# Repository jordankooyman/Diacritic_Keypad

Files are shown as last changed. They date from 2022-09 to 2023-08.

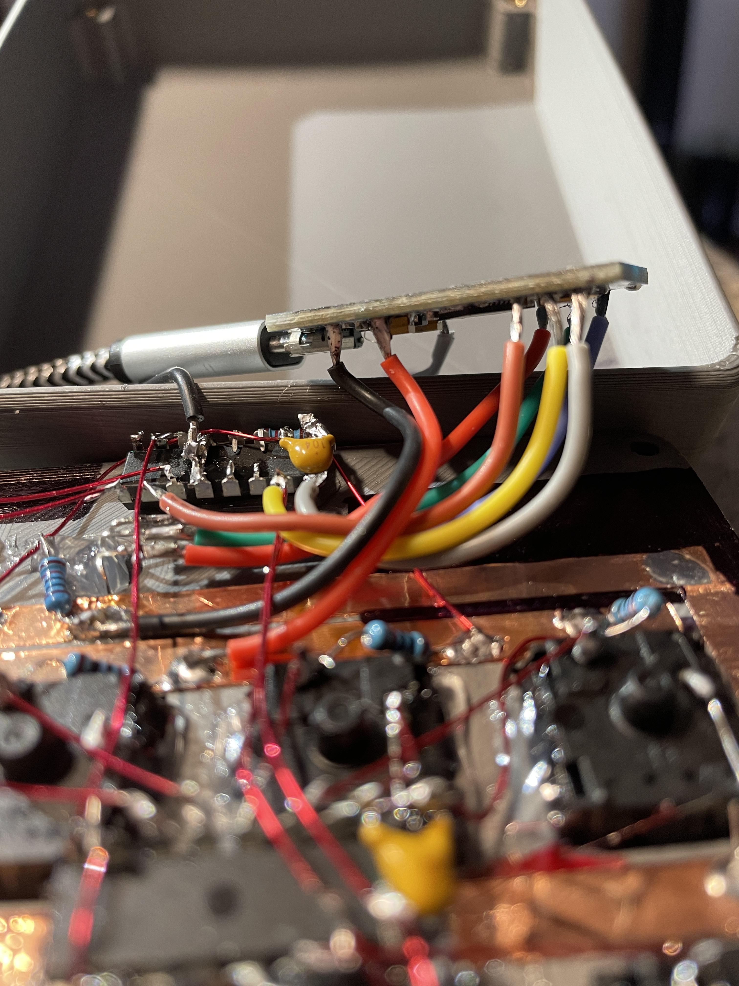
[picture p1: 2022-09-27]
Example Wiring Photos/Full Wiring with Capacitors (4).JPG

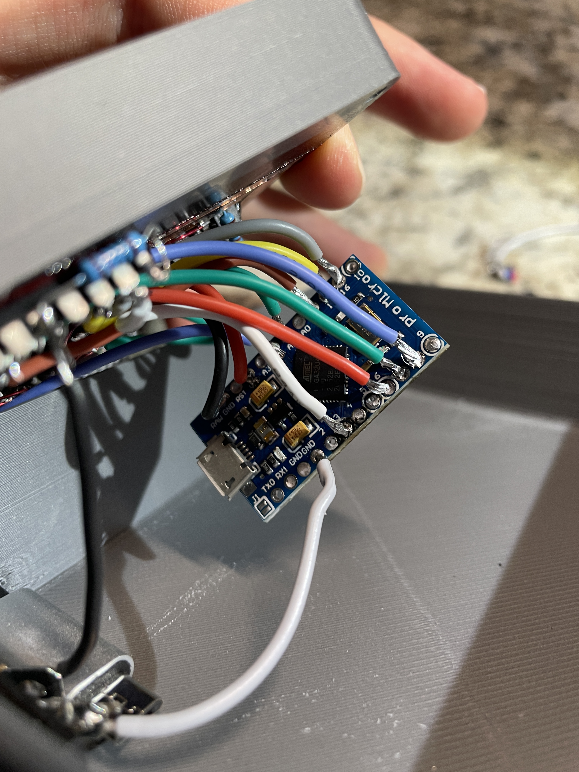
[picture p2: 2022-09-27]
Example Wiring Photos/Arduino Wiring (8).JPG

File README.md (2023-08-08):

# Diacritic_Keypad
An Arduino-based custom keyboard for more easily typing diacritic letters, particularly on Windows, but with support for many Linux distros as well.

Written for Arduino Pro Micro/Arduino Leonardo boards
Intended for use with 17 buttons and a switch, all connected to the arduino via chained shift registers
diacritc keypad finished perspective view

Bill of Materials (BOM):

    1x  RGB LED (common negative) for status indication at runtime
    17x Cherry MX Red keyswitches were used in my build, but any Cherry MX keyswitch should be compatible
    1x  Power switch style toggle switch (acts as Linux/Windows mode switch)
    3x  74HC165 Parallel to serial Shift Registers were used
    3x  0.1uF ceramic capacitors to stabalize shift registers
    1x  1uF electrolytic capacitor to handle larger current spikes - exact value not too important, can be larger
    1x  Arduino Pro Micro
    1x  6ft Micro USB to USB cable (glued in)
    19x 10k Resistors
        26awg Enamled copper wire for keyswitch connections
        Copper Foil tape for positive and negative bus bars (optional, but recommended)
        24awg Insulated copper wire for connections to arduino
        Pin headers to connect to arduino (optional)
        Hot Glue to hold in keyswitches and insulate shift registers
    4x  M3 brass heat-set inserts
    4x  M3 by 8mm bolts to hold everything closed
    1x  Case Set (case and insert) - must be 3D Printed (material choice not important)
    4x  Rubber Feet (optional)
    17x Keycaps (can be 3D Printed (material not important), sample files included)
diacritc keypad finished top view

All CAD files and example wiring pictures are included.
A sample set of keycaps is also included.
The two component reference pictures were sourced online, all other materials were made by Jordan Kooyman.

Basic wiring:  (Look at Example Wiring Photos folder included in this repo for an example)

    Every keyswitch (and toggle switch) is connected to GND (0V) directly.
    The other terminal on every keyswitch (and toggle switch) is connected to 1 data input pin on a shift register, with a 10k resistor also connecting that to Vcc (5V)
    The clock input pin on all 3 shift registers is connected together
    The parallel load input pin on all 3 shift registers is connected together
    The serial output pin of the shift register with only 2 connections is connected to the serial input pin of one of the other 2 shift registers
    Then, the serial output pin of that shift register is connected to the serial input pin of the final shift register
    The serial output, clock input, and parallel load input pins are all connected to I/O pins of the arduino
    Each shift register also needs the Vcc pin connected to Vcc (5V), GND to GND (0V), and Clock Enable connected to GND (0V)
    The common negative pin of the RGB LED is connected to a 10k resistor that is then connected to GND (0V)
    The other 3 pins of the RGB LED are connected to the I/O pins of the arduino
    The GND (0V) bus is conencted to a GND pin on the arduino
    The Vcc (5V) bus is conencted to the Vcc pin on the arduino
        Note: I recommend leaving some extra length on the wires that need to go from the top to the bottom (or vice versa) to
        make working on this easier (but make sure the case can still close)
    The electrolytic capacitor is connected between VCC (5v) and GND (0V) busses somewhere (ensure correct polarity, strip is negative pin)
    1 ceramic capacitor is connected between GND (0V) and the Vcc input pin of each shift register

Here is a video of me wiring my keypad together, uncut but running at 2x speed: https://youtu.be/HU2RTQba6jM

Due to the variability of wiring and desired character outputs, the code included is incomplete and all character combinations must be written in manually.

# Prevent Code Uploads
This keypad, as currently designed, will always still appear as an arduino device when connected to a computer. To change how it appears, but not restrict reprogrammability at all, the VID and PID values can be modified for the profile being uploaded to the board. To restrict reprogramming, some COM ports related to the attatched can be disabled in Windows, but it is local to each PC. To better restrict programming, an external ISP such as a usbTinyISP can be used to upload a the code and overwrite the bootloader of the Arduino Pro Micro. Note that overwriting the bootloader means that the ISP must be used to upload code to the board again in the future, until a bootloader is reloaded. Traditional methods of disabling sketch uploading to arduino boards do not work for the Atmega32u4 since it has built-in usb support rather than using an external chip, however this may be different if you are using a different microprocessor. For more information, please do your own research for the specific board you are using.

# Design and Wiring Advice
When designing your own case, it is important to keep in mind both how to assemble it and where all the wiring will go inside. Make sure to leave enough room on the inside to fit all the wires and the microcontroller such that no wires inadvertently short out once assembled, which may cause permanent damage to the microcontroller or worse. To make this easier, it is recommended to make the whole case from plastic rather than metal. If making the case from metal, make sure to insulate all connections to prevent short circuits (and be careful using the copper foil tape bus bar design demonstrated above since those tapes often feature a conductive adhesive). Before doing the final assembly of the project, make sure to carefully assembly throughout the build process to ensure everything will still fit together and nothing will short circuit. It is also recommended to test the wiring throughout, which can be accomplished by uncommenting the TestMode line in the code provided (it is uncommented as provided here) before testing all the parts believed to be fully functional while the device is plugged into a computer with Arduino IDE and the serial monitor open on the correct port.
While wiring, try to keep the wires organized. It is recommended to mark them if they are not unique, and to write down where each one goes until it can be fully connected. Also ensure the wires are long enough to reach to their destination and the device can still be opened, but not so long that there is a lot of extra wire when attempting to assemble the device.

# Testing Guide
To test operations of the device as well as to determine the button layout, the built-in TestMode allows you to see what the microcontroller reports when a button is pressed. This can be seen with the serial monitor running (included in Arduino IDE) with the device connected to that computer via USB. If any anomalies appear, such as a button not showing it is pressed, or always being pressed, or 1 button being pressed shows multiple buttons being pressed, the first thing that should be done is to verify the wiring is correct. Do this by using a multimeter with a continuity test and check both connections that should exist and connections that should not. If nothing can be found, check again with the serial monitor while the device is open for testing, as short circuits may occur only while assembled. If no faults can be found in the wiring, check the code to ensure it is reading the buttons correctly, particularly any changes you have made. Another common issue is not updating the pins that are used, which can lead to erratic behavior.

# Disclaimers
This project is licensed under GPLv3. As such, you are free to use this project and modify it as you see fit, both privately and commercially. However, if used commercially, the product must disclose this project as its source as well as all changes made. For more information, please check out the license directly.
You are fully responsible and liable for any faults, issues, damage, or other problems for any devices you make. Make at your own risk.

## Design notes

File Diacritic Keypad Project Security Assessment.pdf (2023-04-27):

Security Assessment – Diacritic Keypad

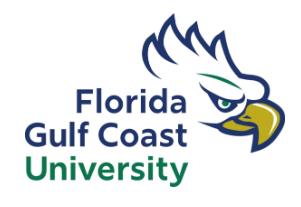
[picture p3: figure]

### Open-Source Keypad for Diacritic Characters

# Security Assessment Report

### Version 1.0

### April 27, 2023

Page ii

## Table of Contents

## 1. Summary

We have determined that the security of the open-source Diacritic Keypad project was mediocre through product observation and white box testing. The major issues were centered around lack of explanation of systems over bad design or implementation.

## 1. Assessment Scope

Arduino IDE on Windows 10 and Windows 11 was utilized during testing, with the C project code being tested. GitHub was tested through Firefox, Edge, and Chrome, focusing primarily on the content more than the formatting.

## 2. Summary of Findings

Of the findings discovered during our assessment, 1 was considered High risk, 0 Moderate risks, 2 Low, and 5 Informational risks. The SWOT used for planning the assessment are broken down

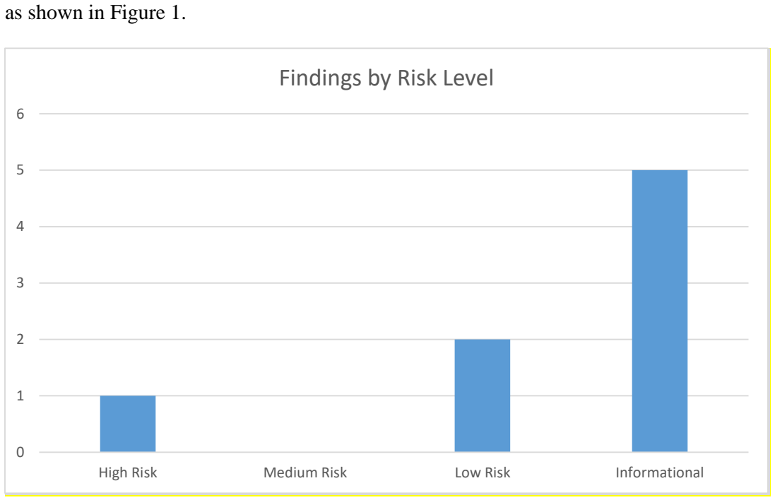
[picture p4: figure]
as shown in Figure 1.; High Risk; Medium Risk; Low Risk; Informational; Findings by Risk Level

Figure 1. Findings by Risk Level

The top risk was a simple issue that the code of the device when finalized can still be easily overwritten, leading to many issues for the end user, and the potential for dangerous security vulnerabilities to be added to an otherwise secure computer. The remaining risks were either already handled or were more minor changes focused on improving the explanations with the project.

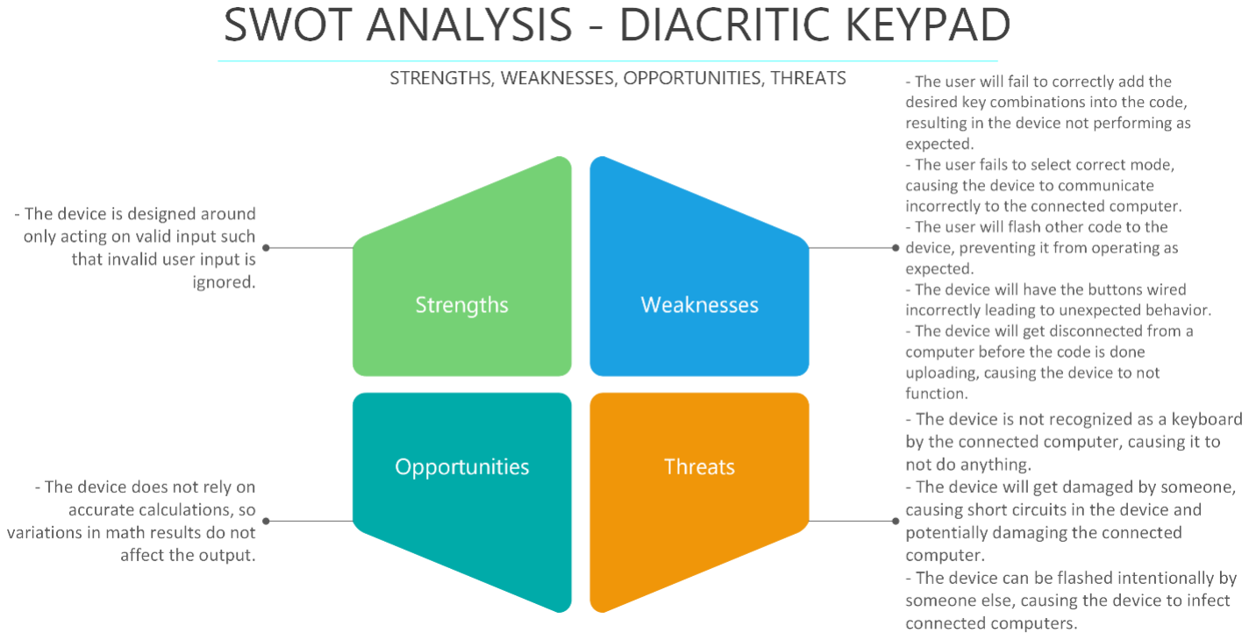
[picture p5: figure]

Figure 2. SWOT

The issues related to code being overwritten and bad assembly of project were addressed from the SWOT shown in Figure 2.

## 3. Summary of Recommendations

The provided supporting documentation and content needs to be improved to address assumptions made during the initial project, particularly focusing on assumed prior knowledge of electronics, wiring, and general safe practices of people considering attempting the project. Some guides have been built to address these issues, but more depth needs to be added to certain sections, such as modifying the code, as well as adding video-based content to demonstrate safe practices and techniques.

## 2. Goals, Findings, and Recommendations

## 1. Assessment Goals

The purpose of this assessment was to do the following:
- Ensure that the system was in compliance with basic user security as defined in CEN 3078.
- Determine if the application was securely built.
- Assess necessary corrective measures to reduce or eliminate identified issues.

## 2. Detailed Findings

Type | Severity | Detailed Finding
Weakness | Informational | The project code uses several C-style arrays throughout to store state data and reference keys. These arrays are easy to look beyond the bounds of as they decay to pointers readily, as discussed in CEN 3073 lecture on March 30th, 2023, particularly in loops, which is how this project utilizes the arrays.
Threat | Informational | The project is based on responding to user input, and not all inputs are valid, since only specific combinations of keys will produce a valid diacritic character, so faulty user input must be considered in every section that takes input from the user to ensure all scenarios are handled, even unexpected scenarios.
Threat | Moderate Risk

The code stored on hobby use microcontrollers such as the recommended Arduino Pro Micro have a built-in bootloader to allow for code to be easily uploaded when a computer is connected, as discussed online in the forum thread “Arduino pro Micro -Is It Possible to Remove the Bootloader While Flashing Using the Bootloader?”. However, this project intends to leave the microcontroller always connected to the computer, therefore code can always be written to it, overwriting the previous code, which can lead to unintended outcomes if the device is completed and another project’s code gets uploaded to this device.

Weakness | High Risk | The project code assumes that the pins defined at the top are correct, and if they are not updated to match each instance of the project built, the project may not work as intended or at all, as the communication wires expected are not actually there, but the code has no checks for such a condition.
Weakness | High Risk | The project requires that everything is wired correctly with no short circuits and the correct components. If this is not the case, the project is very likely to not function at all and even has the risk to physically damage components including the microcontroller and potentially also connected computers.
Threat | Observation | This project’s code includes 1 library, ‘Keyboard.h’. Since this library is included, the security of it must also be assessed since it is adding code to the project as well as being actively and extensively used in the project. However, due to the scale of the Arduino Pro Micro and the wide variance of it, there is very little focus on security holes in the library that may exist, as seen in the issues for the code on GitHub (“Issues · Arduino-Libraries/Keyboard.”). Most focus is instead pointed towards how the library can be used in security attacks on other systems, as seen by the research done by Seth Helgeson, et al., among many others.
Threat | Observation | The design of the project, particularly the case for the project, is very important as well. A poorly designed case will not hold things tightly and securely together, leading to the wires potentially getting ripped off, crushed, broken, touching each other (short circuit), or otherwise being exposed to being damaged over time. Many of these issues will not appear immediately but will instead manifest over time, leading to erratic behavior long after the project is completed, making the issue hard to identify for inexperienced users.
Weakness | Low Risk | This project features only minimal logging in the form of a debugging and test mode that can be enabled and disabled within the code. Additionally, even when this logging is occurring, a serial monitor must be running on an attached computer in order to see any of the log data as it occurs, as no information is saved to the microcontroller. Furthermore, no information is logged during normal use.

## 3. Recommendations

1. Add a Design and Wiring Advice section in ReadMe.md to help avoid potential

regulatory issues by advising people to tailor their designs to be safe and not pose a risk of electric shock or could otherwise cause damage to other systems. Ease of fix:

Moderately Difficult – guide must be thoroughly written to be most effective.

2. Add a testing guide section in ReadMe.md to provide some basic training on how to test

a project such as this for people with no prior experience. Also explain how to utilize the

basic logging systems included in the provided code, since it is real-time only and done

through the serial monitor in Arduino IDE. Ease of fix: Moderately Difficult – guide

must be thoroughly written to be most effective.

3. Update end of ReadMe.md with fair use licensing remark and end user risk disclaimer.

Ease of fix: Easy – simple template to follow, partially provided in GitHub (“Licensing a

Repository.”).

4. Vulnerabilities in included libraries (Keyboard.h). Perform extensive online research to

identify any known and relevant security vulnerabilities included in that library. Ease of

fix: Moderately Difficult – must check many sources and patch notes for issues.

5. Physical security of actual hardware. Add a disclaimer in the project ReadMe.md to make

users aware of the risks they must consider for their situation when designing and

building this product. Ease of fix: Easy – not an extensive guide, just a disclaimer.

6. Fix product code being overwritten. Update the ReadMe.md file of the project detailing

different things that can be done to reduce or eliminate this vulnerability. Ease of fix:

Moderately Difficult – guide must be thoroughly written for users not familiar with

alternative bootloader tools (“Disabling Skethc Uploading on Arduino pro Micro.”).

7. Add security design considerations section (including issues with adding wireless

connectivity). Ease of fix: Moderately Difficult – many scenarios to consider, but not an

extensive guide.

8. Update logging option to code, primarily for debugging, but with EEPROM as an option

if desired. Ease of fix: Difficult – need to restructure code and deal with creating and

exporting files.

## 3. Methodology for the Security Control Assessment

### 3.1.1 Risk Level Assessment

Each Business Risk has been assigned a Risk Level value of High, Moderate, or Low. The rating is, in actuality, an assessment of the priority with which each Business Risk will be viewed. The definitions in Error! Reference source not found. apply to risk level assessment values (based on probability and severity of risk). While Table 2 describes the estimation values used for a risk’s “ease-of-fix”.

Table 1 - Risk Values
Rating | Definition of Risk Rating
High Risk | Exploitation of the technical or procedural vulnerability will cause substantial harm to the business processes. Significant political, financial, and legal damage is likely to result
Moderate Risk | Exploitation of the technical or procedural vulnerability will significantly impact the confidentiality, integrity and/or availability of the system, or data. Exploitation of the vulnerability may cause moderate financial loss or public embarrassment to organization.
Low Risk | Exploitation of the technical or procedural vulnerability will cause minimal impact to operations. The confidentiality, integrity and availability of sensitive information are not at risk of compromise. Exploitation of the vulnerability may cause slight financial loss or public embarrassment
Informational | An “Informational” finding, is a risk that has been identified during this assessment which is reassigned to another Major Application (MA) or General Support System (GSS). As these already exist or are handled by a different department, the informational finding will simply be noted as it is not the responsibility of this group to create a Corrective Action Plan.
Observations | An observation risk will need to be “watched” as it may arise as a result of various changes raising it to a higher risk category. However, until and unless the change happens it remains a low risk.

Table 2 - Ease of Fix Definitions
Rating | Definition of Risk Rating
Easy | The corrective action(s) can be completed quickly with minimal resources, and without causing disruption to the system or data
Moderately Difficult | Remediation efforts will likely cause a noticeable service disruption • A vendor patch or major configuration change may be required to close the vulnerability • An upgrade to a different version of the software may be required to address the impact severity • The system may require a reconfiguration to mitigate the threat exposure • Corrective action may require construction or significant alterations to the manner in which business is undertaken
Very Difficult | The high risk of substantial service disruption makes it impractical to complete the corrective action for mission critical systems without careful scheduling • An obscure, hard-to-find vendor patch may be required to close the vulnerability

Rating | Definition of Risk Rating
| • Significant, time-consuming configuration changes may be required to address the threat exposure or impact severity • Corrective action requires major construction or redesign of an entire business process
No Known Fix | No known solution to the problem currently exists. The Risk may require the Business Owner to: • Discontinue use of the software or protocol • Isolate the information system within the enterprise, thereby eliminating reliance on the system In some cases, the vulnerability is due to a design-level flaw that cannot be resolved through the application of vendor patches or the reconfiguration of the system. If the system is critical and must be used to support on-going business functions, no less than quarterly monitoring shall be conducted by the Business Owner, and reviewed by IS Management, to validate that security incidents have not occurred

### 3.1.2 Risk Assessment

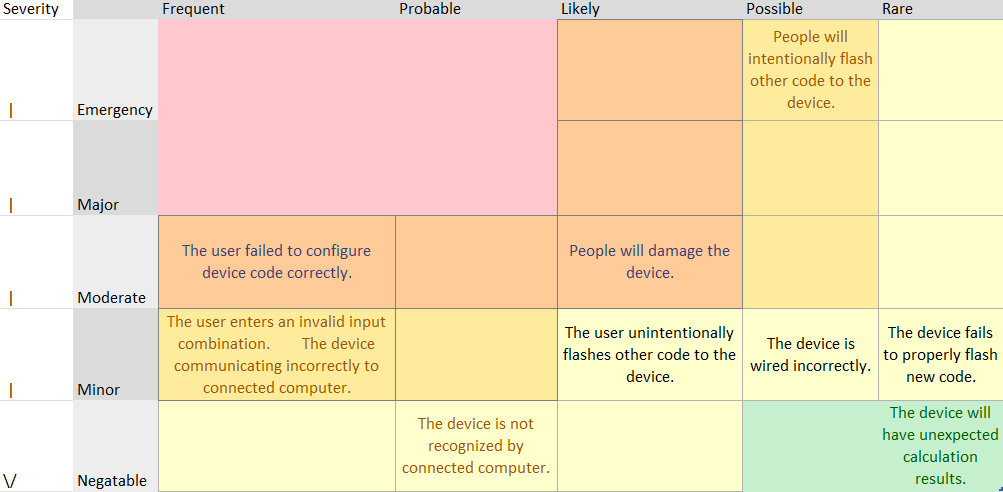
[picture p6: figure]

explain accuracy of it (what was and what wasn’t)

### 3.1.3 White Box Testing

This was completed by checking both known-valid and known-invalid inputs on the device and verify the code can handle the all the inputs without breaking or otherwise working in unexpected or undocumented ways.

### 3.1.4 Tools Used

This was completed using Arduino IDE’s Serial Monitor and dedicated serial port logging code in the project. Used to verify all button inputs work as expected, as well as key layout is known, and that there are no logical errors within the code, particularly since this part is defined by the end user and cannot be tested ahead of time.

### 3.1.5 Arduino Vulnerabilities

There are few major vulnerabilities in the Arduino hardware, specifically the Arduino Pro Micro, based on the ATMega32u4 processor. There are also no known vulnerabilities in the only included file in the C code of the project, Keyboard.h, at least as reported to the library’s issues tracker in GitHub (“Issues · Arduino-Libraries/Keyboard.”). There is currently very little interest in trying to hack these devices and libraries since they simply are not widespread enough nor containing valuable enough information for most hackers to target these, instead they may focus on consumer units that are similar but using different code and hardware (“Security Risk of Emulating Hid Devices with ATmega32U4 Devices.”). The only major attention focused on these type of devices is how they can be utilized in attacks of other systems, primarily when a USB port can be accessed (Helgeson, Seth, et al.).

## 4. Figures and Code

### 4.1.1 Processing Cycle Flowchart

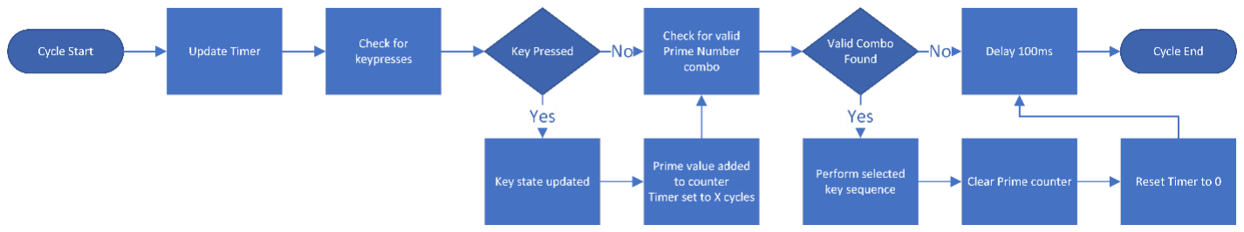
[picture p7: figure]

The processing flowchart shown above describes the execution path of the project code in a high level, including the branches reacting to user input, when it is given.

### 4.1.2 Project Build and Test Flowchart

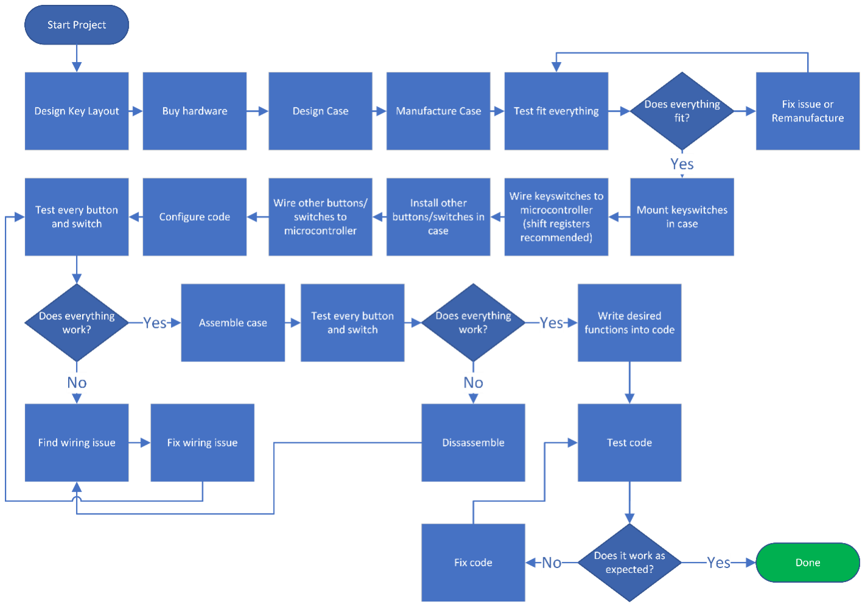
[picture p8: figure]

The flowchart above details all the steps for completing this project as an outside user. Includes all steps between starting the project and having a complete and working product. The process has many points for users to make changes, necessitating several checks throughout that cannot be done by the project itself.

### 4.1.3 Sample Logging Code

// Print out extra debug information if enabled #ifdef ExtendedTestMode
Serial.print("Button Index: "); Serial.print(button);
Serial.print(" Value: ");
Serial.println(value);
#endif

The code snippet shown above is a sample of the logging code currently in the project’s code. This section and several others could be expanded to include writing to an internal file. In adding that feature, another function would also need to be added for exporting that internal file to a computer to be used for debugging or maintenance.

## 5. Works Cited

“Arduino pro Micro - Is It Possible to Remove the Bootloader While Flashing Using the Bootloader?” Arduino Stack Exchange, arduino.stackexchange.com/questions/90543/is-it-possible-to-remove-the-bootloader-while-flashing-using-the-bootloader. Accessed 26 Apr. 2023.
“Disabling Skethc Uploading on Arduino pro Micro.” Arduino Forum, 2 Nov. 2022, forum.arduino.cc/t/disabling-skethc-uploading-on-arduino-pro-micro/1048808. Accessed 26 Apr. 2023.
“Issues · Arduino-Libraries/Keyboard.” GitHub, github.com/arduino-libraries/Keyboard/issues?q=is%3Aissue. Accessed 26 Apr. 2023.
“Licensing a Repository.” GitHub Docs, docs.github.com/en/repositories/managing-your-repositorys-settings-and-features/customizing-your-repository/licensing-a-repository#disclaimer.
“Security Risk of Emulating Hid Devices with ATmega32U4 Devices.” Arduino Forum, 5 July 2021, forum.arduino.cc/t/security-risk-of-emulating-hid-devices-with-atmega32u4-devices/881892. Accessed 26 Apr. 2023.
Helgeson, Seth, et al. Wireless Exploitation through Keyboard Emulation. Athens: The Steering Committee of The World Congress in Computer Science, Computer Engineering and Applied Computing (WorldComp), 2018. ProQuest. Web. 26 Apr. 2023.
Week 11 Lecture – March 30th
- about code vulnerabilities (c-style arrays and pointers)

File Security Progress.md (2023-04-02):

Security Fixes:
1. Vulnerabilities in included libraries. I only include 1 library in this code (Keyboard.h). After extensive online research, I have found no known relevant security vulnerabilities included in that library. Therefore, no changes need to be considered in the code regarding this library.
2. Physical security of actual hardware. Due to the nature of the product and project, very little can be done to improve the physical security of each keypad. This is because this project focuses on providing a design for a keypad that other people can use as a starting point and modify to meet their needs. Therefore, the target use case is very broad and involves very different physical security considerations, thus it will go against the nature of the project to include physical security precautions in the design. However, a disclaimer was added in the ReadMe.md file of the project in [commit e0c8cb9](https://github.com/jordankooyman/Diacritic_Keypad/blob/e0c8cb98c9d53e41b8528363b02cca5fffdffaf5/README.md).
3. Fix product code being overwritten. To prevent the code from being overwritten accidentally or maliciously, several methods have been added to the ReadMe.md file of the project detailing different things that can be done to reduce or eliminate this vulnerability. These were added in [commit e0c8cb9](https://github.com/jordankooyman/Diacritic_Keypad/blob/e0c8cb98c9d53e41b8528363b02cca5fffdffaf5/README.md).

Upcoming Fixes:
1. Add security design considerations section (including issues with adding wireless connectivity). Priority: Mid Difficulty: Moderate
2. Add tutorial sections for different ways to fix code overwrite problem. Priority: High Difficulty: Moderate
3. Add logging option to code, primarily for debugging, but with EEPROM as an option if desired. Priority: Low Difficulty: Difficult
4. Add suggested product test procedure to project to help with debugging and building. Priority: Mid Difficulty: Easy

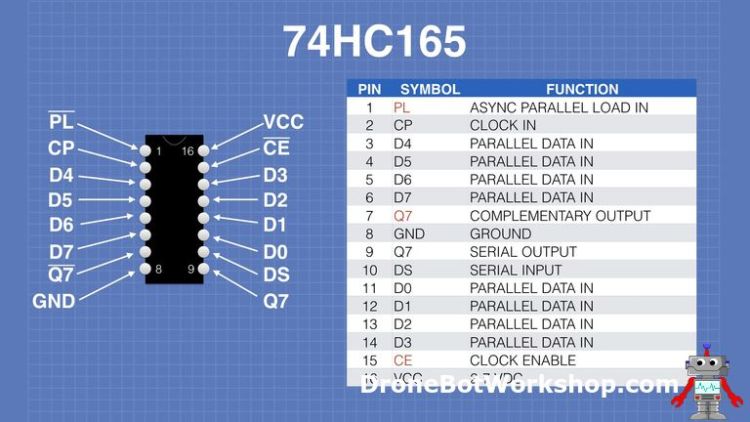
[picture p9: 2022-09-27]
Example Wiring Photos/74HC165-pinout.jpeg

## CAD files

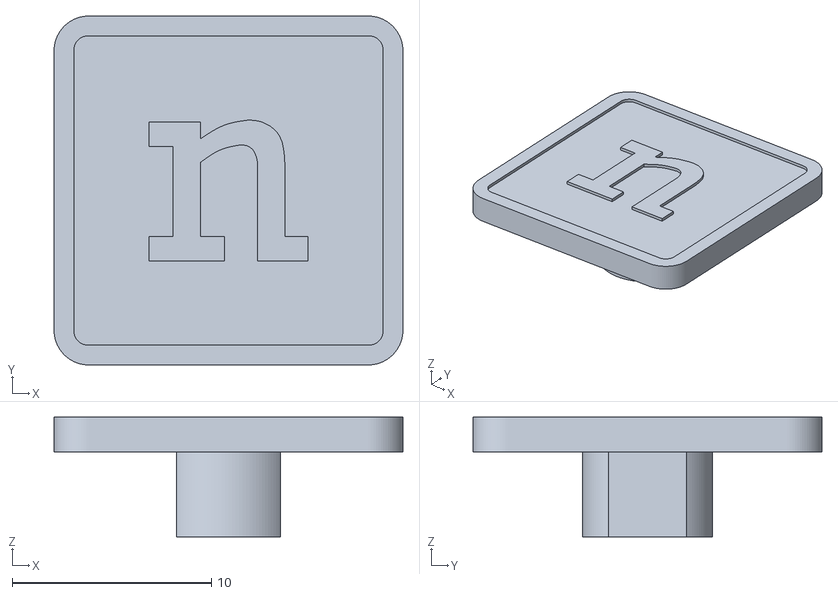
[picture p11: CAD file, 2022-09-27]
3D CAD Files/Diacritic Keycaps (Sample)/n Keycap.obj
17.5 x 17.5 x 6.00

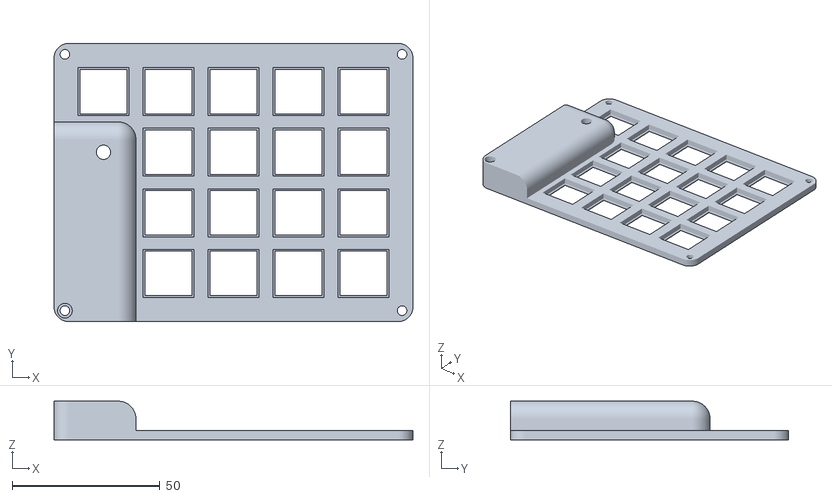
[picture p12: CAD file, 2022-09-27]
3D CAD Files/Key Insert.stl
121.5 x 94.2 x 13.1

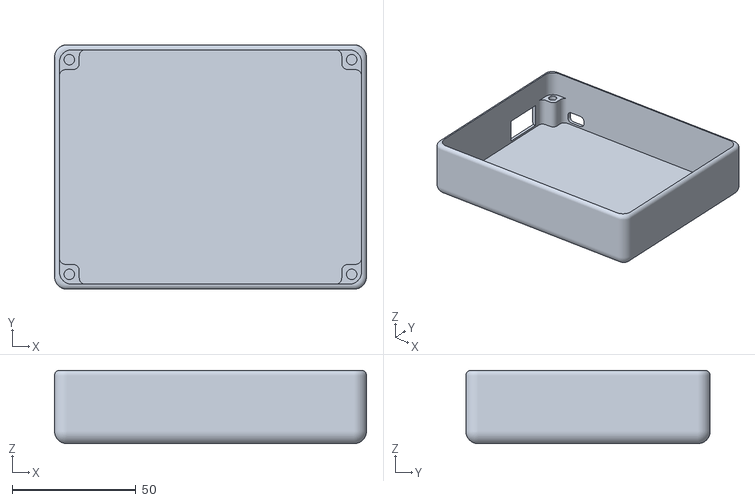
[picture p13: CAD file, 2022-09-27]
3D CAD Files/Case.stl
126.1 x 98.7 x 29.6

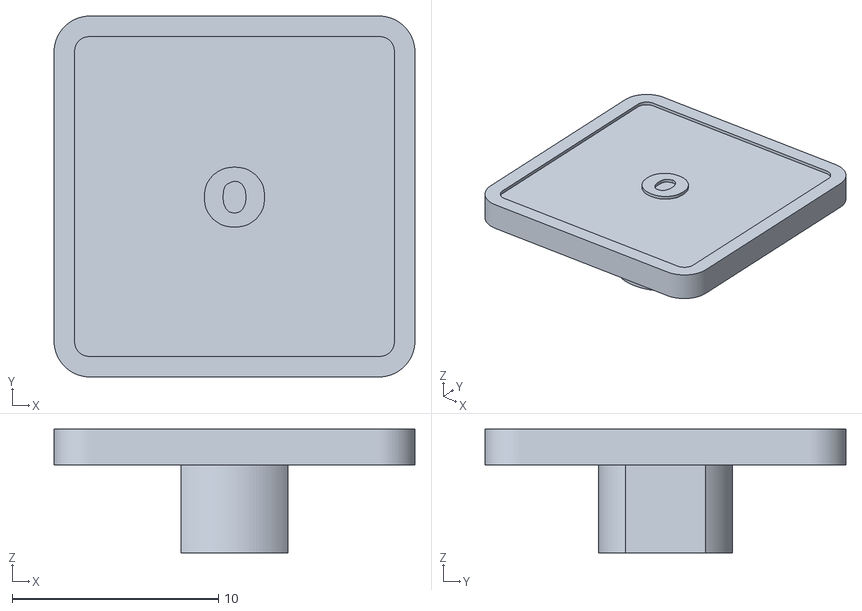
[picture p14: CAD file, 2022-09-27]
3D CAD Files/Diacritic Keycaps (Sample)/O Keyacp.obj
17.5 x 17.5 x 6.00

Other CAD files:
3D CAD Files/Diacritic Keycaps (Sample)/Shift Keycap.obj
3D CAD Files/Diacritic Keycaps (Sample)/e Keycap.obj
3D CAD Files/Diacritic Keycaps (Sample)/c Keycap.obj
3D CAD Files/Diacritic Keycaps (Sample)/a Keycap.obj
3D CAD Files/Diacritic Keycaps (Sample)/o Keycap.obj
3D CAD Files/Diacritic Keycaps (Sample)/u Keycap.obj
3D CAD Files/Diacritic Keycaps (Sample)/i Keycap.obj
3D CAD Files/Diacritic Keycaps (Sample)/' Keycap.obj
3D CAD Files/Diacritic Keycaps (Sample)/'' Keycap.obj
3D CAD Files/Diacritic Keycaps (Sample)/, Keycap.obj
3D CAD Files/Diacritic Keycaps (Sample)/Keycap.obj
3D CAD Files/Diacritic Keycaps (Sample)/^ Keycap.obj
3D CAD Files/Diacritic Keycaps (Sample)/` Keycap.obj
3D CAD Files/Diacritic Keycaps (Sample)/~ Keycap.obj
3D CAD Files/Source Files/Diacritic Keycaps.f3d
3D CAD Files/Source Files/Diacritic Keypad.f3d

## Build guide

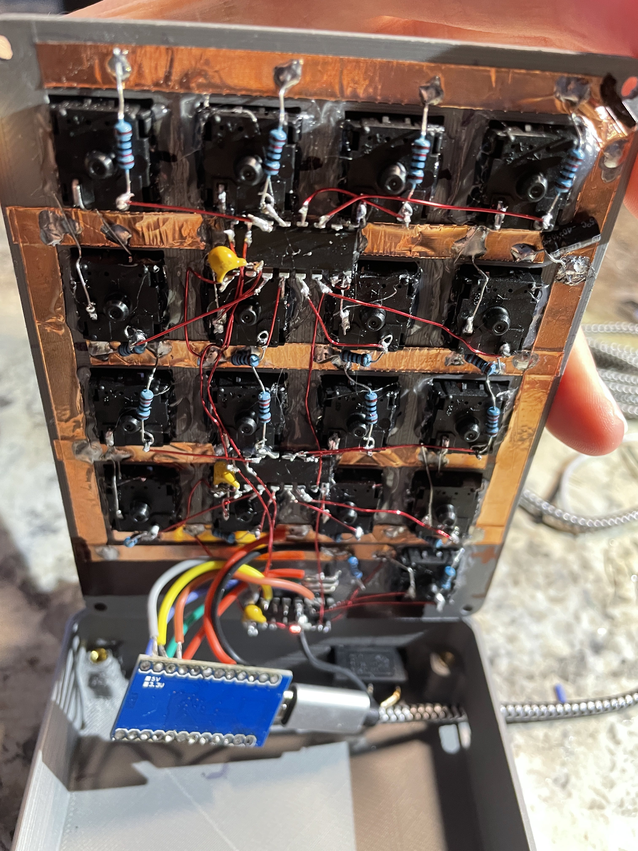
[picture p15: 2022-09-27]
Example Wiring Photos/Full Wiring with Capacitors (8).JPG

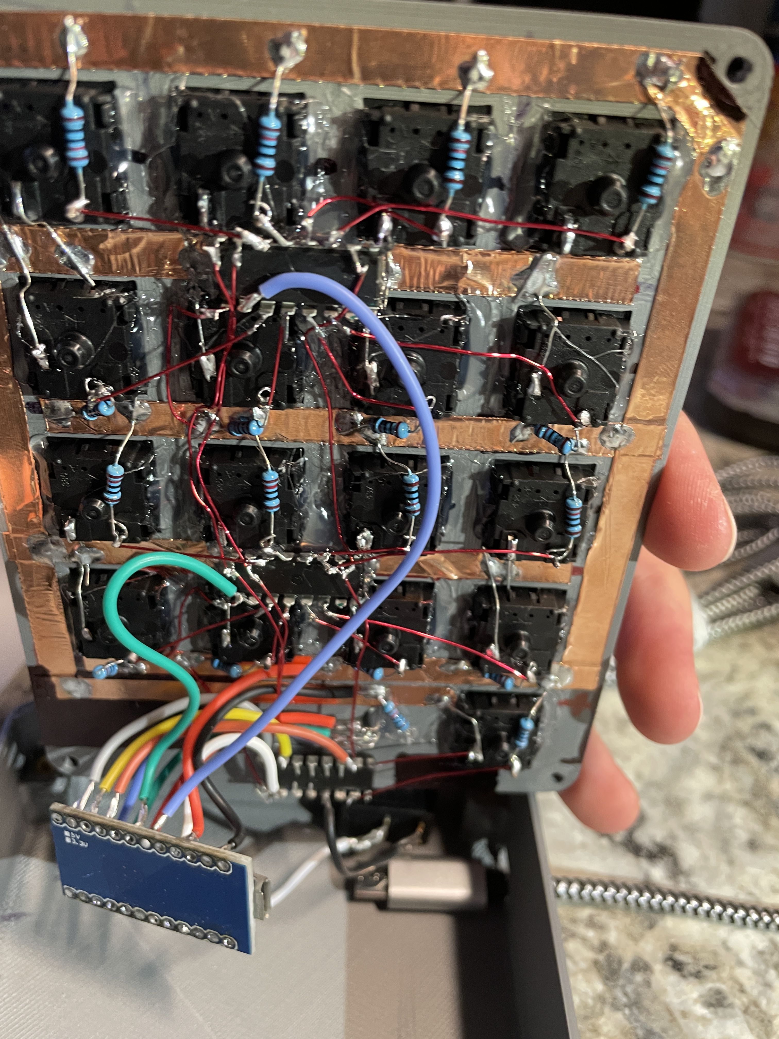
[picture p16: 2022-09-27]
Example Wiring Photos/Arduino Wiring (1).JPG

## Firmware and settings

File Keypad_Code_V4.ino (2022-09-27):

// Diacritic Keypad program by Jordan Kooyman
// Completed 9/27/22
// Written for Arduino Pro Micro/Arduino Leonardo boards
// Intended for use with 17 buttons and a switch, all connected to the arduino via chained shift registers
// Uses 1 RGB LED (common negative) for status indication at runtime
// More information can be found at: https://github.com/jordankooyman/Diacritic_Keypad

// Only 1 sample output is provided using demo numbers, all the output cases (starting at line 180)
//   will need to be written manually once key layout is determined

// Basic Program Configuration:

//Debug Mode Compiler Controls
#define TestMode 1 // Comment out to disable test mode and enable normal keyboard output
#define ExtendedTestMode 1 // Comment out to disable per button press debug information

//Define where each pin is connected to the Ardunio-compatible board
#define PIN_CLOCK 14    // Shift Register Clock Pin
#define PIN_LOADDATA 16 // Shift Register Load Data Pin
#define PIN_DATAIN 15   // Shift Register Data Output Pin
                        // Shift Register Enable Pin -> connect to VCC (5V) to always enable
#define PIN_RED 6       // RGB LED Red leg
#define PIN_GREEN 7     // RGB LED Green leg
#define PIN_BLUE 8      // RGB LED Blue leg

// Keyboard ID/index layout: - Verify using extended test mode (dependent on wiring)
//    0     9   2  17  10
//    1     8   3  16  11
//          7   4  15  12
//          6   5  14  13
// Keyboard Prime Mapping:   - Rearrange as needed such that prime numbers are increasing as key id increases
//         19   2  53  23
//         17   3  47  29
//         13   5  43  31
//         11   7  41  37
// Keyboard Key Mapping:     - Fill in after desired key layout has been determined
// Shift    ?   ?   ?   ?
//  Mode    ?   ?   ?   ?
//          ?   ?   ?   ?
//          ?   ?   ?   ?

const int primeTable[16] = {2,3,5,7,11,13,17,19,23,29,31,37,41,43,47,53}; // Used to decode combination in switch statement
  // Corresponding keys:  ?,?,?,?, ?, ?, ?, ?, ?, ?, ?, ?, ?, ?, ?, ?
int buttonState[18] = {-1,-1,-1,-1,-1,-1,-1,-1,-1,-1,-1,-1,-1,-1,-1,-1,-1,-1}; 
// Corresponding keys:  ?, ?, ?, ?, ?, ?, ?, ?, ?, ?, ?, ?, ?, ?, ?, ?, ?, ?

// Debugging Mode Indicator Outputs
#define WINDOWS_OUTPUT "Windows: "
#define LINUX_OUTPUT "Linux: "

// End of Basic Program Configuration

// Advanced Program Configuration, No Changes Recommended

// Define numpad constants for windows altcode usage - https://www.reddit.com/r/arduino/comments/c3cl41/keyboard_library_using_alt_keycodes_trouble/
// Custom data type to simplify handling of numpad inputs for Windows altcode combinations
enum NumPad {
  N_SKIP = -1,    // Skip given key for output
  N_1 = 0xE1, // Keypad 1 and End
  N_2 = 0xE2, // Keypad 2 and Down Arrow
  N_3 = 0xE3, // Keypad 3 and PageDn
  N_4 = 0xE4, // Keypad 4 and Left Arrow
  N_5 = 0xE5, // Keypad 5
  N_6 = 0xE6, // Keypad 6 and Right Arrow
  N_7 = 0xE7, // Keypad 7 and Home
  N_8 = 0xE8, // Keypad 8 and Up Arrow
  N_9 = 0xE9, // Keypad 9 and Page Up
  N_0 = 0xEA  // Keypad 0 and Insert
};


#ifndef TestMode
#include <Keyboard.h> // https://www.arduino.cc/reference/en/language/functions/usb/keyboard/
#endif

bool Shift = false;
bool OS = false; //False: Windows  |  True: Linux
int value;
int total;
unsigned long clock;

// Windows altcodes, with support for 3 or four digits
void pressWindows(String output, NumPad key1, NumPad key2, NumPad key3, NumPad key4 = N_SKIP); 
// Linux altcode handled with unicode hex values (0-9 and A-F, case sensitive)
void pressLinux(String output, char key1, char key2, char key3, char key4);

void setup() { //Initialize pins as i or o for test-proofing
  pinMode(PIN_CLOCK, OUTPUT);
  pinMode(PIN_LOADDATA, OUTPUT);
  pinMode(PIN_DATAIN, INPUT);
  pinMode(PIN_RED, OUTPUT);
  pinMode(PIN_GREEN, OUTPUT);
  pinMode(PIN_BLUE, OUTPUT);
  #ifdef TestMode
  Serial.begin(9600);
  #else
  Keyboard.begin();
  #endif
}

// End of Advanced Program Configuration

void loop() {
  value = -1;
  digitalWrite(PIN_CLOCK, 1); //Initializes pins to low each cycle to avoid false positives
  digitalWrite(PIN_RED, 0);
  digitalWrite(PIN_GREEN, 0);
  digitalWrite(PIN_BLUE, 1);
  digitalWrite(PIN_LOADDATA, 0); // Load data into shift registers
  digitalWrite(PIN_CLOCK, 0);
  digitalWrite(PIN_CLOCK, 1);
  digitalWrite(PIN_LOADDATA, 1);
  
  //Update LED Status to default (red) and reset running total to 1 if timer expires (no longer greater than system timer)
  if (clock <= millis())
  {
    digitalWrite(PIN_RED, 1);
    digitalWrite(PIN_GREEN, 0);
    digitalWrite(PIN_BLUE, 0);
    total = 1;
    #ifdef TestMode
    Serial.println("LED Red");
    #endif
  }

  for (int button = 0; button < 18; button++) { // Load in 18 bits of data from the 3 shift registers connected as 1 24 bit register
    if (button == 2) { // skip the unused pins on the first shift register
      digitalWrite(PIN_CLOCK, 0);
      digitalWrite(PIN_CLOCK, 1); 
      digitalWrite(PIN_CLOCK, 0);
      digitalWrite(PIN_CLOCK, 1);
      digitalWrite(PIN_CLOCK, 0);
      digitalWrite(PIN_CLOCK, 1);
      digitalWrite(PIN_CLOCK, 0);
      digitalWrite(PIN_CLOCK, 1);
      digitalWrite(PIN_CLOCK, 0);
      digitalWrite(PIN_CLOCK, 1);
      digitalWrite(PIN_CLOCK, 0);
      digitalWrite(PIN_CLOCK, 1);
    }
    // Read in the next bit of data from the shift registers
    value = digitalRead(PIN_DATAIN);

    //Determine if the button state has changed, if so store the change and optionally output debug info to serial monitor
    if(buttonState[button] != value)
  { //Potentially add a flag to send to processing
      buttonState[button] = value;
    if (button == 0) Shift = value; // If shift button state changes, update the shift flag
    else if (button == 1) OS = value; // If the OS switch state changes, update the os flag
    else if (value) // If a regular button is pressed, multiply the running total by its prime number and update LED
    {
      total *= primeTable[button-2]; 
      clock = millis() + 1000; // Add 1,000 milliseconds to the timer and set LED to blue
      digitalWrite(PIN_RED, 0);
      digitalWrite(PIN_GREEN, 0);
      digitalWrite(PIN_BLUE, 1);
      #ifdef TestMode
      Serial.println("LED Blue");
      #endif
    }
  // Print out extra debug information if enabled
  #ifdef ExtendedTestMode
    Serial.print("Button Index: ");
    Serial.print(button);
    Serial.print("    Value: ");
    Serial.println(value);
  #endif
    }

    //Pulse the clock to get next bit of data
    digitalWrite(PIN_CLOCK, 0);
    digitalWrite(PIN_CLOCK, 1);
  }
  
  
  //Start processing the data here  
  bool validCombo = false;


  // Every combination needs to be added within the following statement (inside the { })
  // Each different combination needs a new case, but uppercase and lowercase are handled in the same block
  // It is recommended to copy everything starting at 'case (...' to '...break; // end ...' and paste as needed, changing each subsequent block for the next combination
  
  switch (total)
  {
  case (19*17): // begin ae - 19 * 17 [Example case, numbers likely need to be changed]
    if(Shift)       // Uppercase
      if (OS) // Linux
        pressLinux("AE - 00C6", '0', '0', 'C', '6');
      else    // Windows
        pressWindows("AE - 146", N_1, N_4, N_6);
    else            // Lowercase
      if (OS) // Linux
        pressLinux("ae - 00E6", '0', '0', 'E', '6');
      else    // Windows
        pressWindows("ae - 145", N_1, N_4, N_5);
    validCombo = true; // Update Status LED after logic
    break; // end ae - 19 * 17 [Example case, numbers likely need to be changed]
  case 2: // Keep logic going here (remove this line)
    break; // Remove this line as well
  }


  
  
  if(validCombo) // Update status LED if combo found
  {
    total = 1; // Reset running total to 1 to prevent sending repeated inputs
    clock = millis() + 10000; // Add 10,000 milliseconds (10 seconds) to the timer and set LED to green
    digitalWrite(PIN_RED, 0);
    digitalWrite(PIN_GREEN, 1);
    digitalWrite(PIN_BLUE, 0);
    #ifdef TestMode
    Serial.println("LED Green");
    #endif
  }

  delay(100); // Pause execution for 100 milliseconds to keep program running at a reasonable speed (1000/100 = runs nearly 10 times per second)
}


/**
* Processes given altcode to output to Windows through keyboard emulation, with support for 3 or 4 digit altcodes
* Additionally, has a debug mode that can be enabled globally at the top of the code
* @param output - character combination altcode represents, for function debugging and readability
* @param key1 - first number in altcode sequence
* @param key2 - second number in altcode sequence
* @param key3 - third number in altcode sequence
* @param key4 - (optional) fourth number in altcode sequence
* @return void
*/
void pressWindows(String output, NumPad key1, NumPad key2, NumPad key3, NumPad key4) {
  #ifdef TestMode
  Serial.println(WINDOWS_OUTPUT + output);
  #else // Keyboard Output
  Keyboard.press(KEY_RIGHT_ALT);
  
  if (key1 != KEY_SKIP)
    Keyboard.write(key1);
  if (key2 != KEY_SKIP)
    Keyboard.write(key2);
  if (key3 != KEY_SKIP)
    Keyboard.write(key3);
  if (key4 != KEY_SKIP)
    Keyboard.write(key4);
  
  Keyboard.releaseAll();
  #endif
  return;
}


/**
* Processes given hexadecimal unicode to output to many Linux distros through keyboard emulation
* Additionally, has a debug mode that can be enabled globally at the top of the code
* @param output - character combination unicode represents, for function debugging and readability
* @param key1 - first number in hexadecimal unicode sequence
* @param key2 - second number in hexadecimal unicode sequence
* @param key3 - third number in hexadecimal unicode sequence
* @param key4 - fourth number in hexadecimal unicode sequence
* @return void
*/
void pressLinux(String output, char key1, char key2, char key3, char key4) {
  #ifdef TestMode
  Serial.println(LINUX_OUTPUT + output);
  #else // Keyboard Output
  Keyboard.press(KEY_RIGHT_SHIFT);
  Keyboard.press(KEY_RIGHT_CTRL);
  Keyboard.press(KEY_U);
  
  Keyboard.write(key1);
  Keyboard.write(key2);
  Keyboard.write(key3);
  Keyboard.write(key4);
  
  Keyboard.press(KEY_RETURN); // Enter key to close combination
  Keyboard.releaseAll();
  #endif
}

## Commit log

2022-09-27 Update README.md with more complete description
    Added A BoM, wiring description, demo wiring video, and updated other descriptions to better describe the materials being published.
2022-09-27 Added CAD files and Example Pictures
    [' Keycap.obj, '' Keycap.obj, , Keycap.obj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]
2022-10-29 Added Sample Final Product Pictures
    Added finished product photos of the version I built. Will embed near top of README,md
2022-10-29 Update README.md
    Added sample pictures of finished product in description. Rearranged BOM to get keycaps at the bottom, next to the top-down view. Fixed other formatting issues.
